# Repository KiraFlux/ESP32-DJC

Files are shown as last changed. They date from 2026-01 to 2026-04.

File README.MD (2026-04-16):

# ESP32 Dual Joystick Controller (DJC)



An open-source remote controller based on ESP32 with dual analog joysticks, designed for DIY robotics projects.

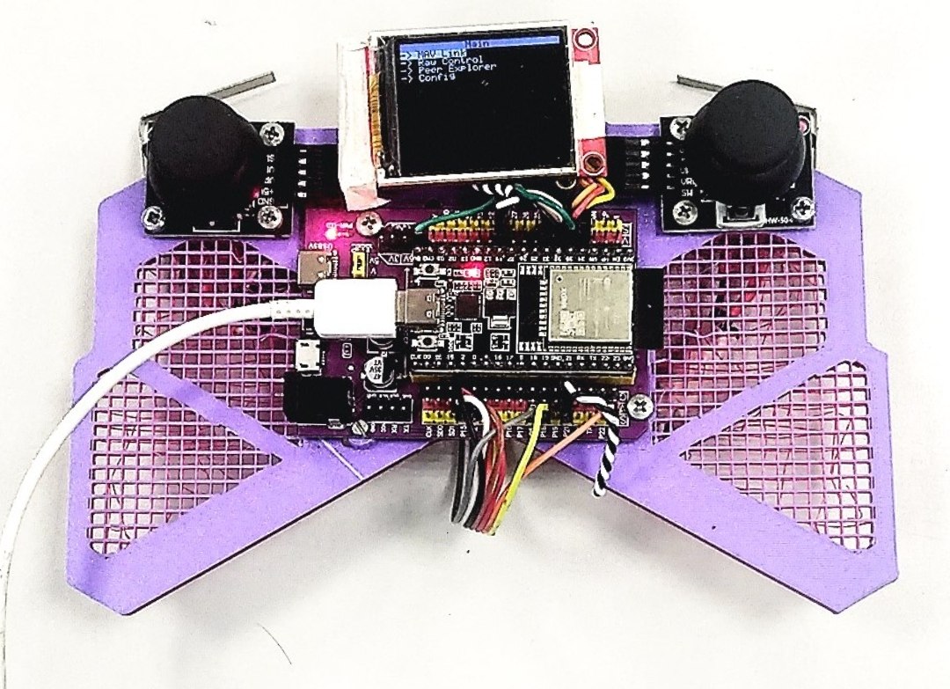
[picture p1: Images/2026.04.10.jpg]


# Software

Firmware is a **PlatformIO** project located in the [`DJC-Firmware`](./DJC-Firmware) directory. All dependencies are declared and managed in [`platformio.ini`](./DJC-Firmware/platformio.ini).

The project uses:
- [KiraFlux/KiraFlux‑Toolkit](https://github.com/KiraFlux/KiraFlux-Toolkit.git)
- [okalachev/MAVLink](https://github.com/okalachev/MAVLink.git)

## Build

A [`makefile`](./DJC-Firmware/makefile) wraps common PlatformIO commands for convenience.

| Command | Action | Note |
| --- | --- | :--- |
| `make` | `pio run` | Compile the project |
| `make u` | `pio run --target upload` | Compile and upload to the ESP32 |
| `make m` | `pio device monitor` | Open serial monitor |
| `make clean` | `pio run --target clean`  | Delete compiled objects |

## Features

| Feature | Status |
| --- | --- |
| Dual joystick with calibration | Implemented |
| ST7735 display (SPI) | Implemented |
| ESPNOW peer discovery & connection | Implemented |
| Raw and MAVLink control modes | Implemented (Basic) |
| Persistent configuration (NVS) | Implemented |
| MAVLink telemetry (partial) | SCALED_IMU, ATTITUDE_QUATERNION, SERIAL_CONTROL messages supported |
| Peer explorer with signal age | Implemented (shows last seen time) |
| On‑screen text input (virtual keyboard) | Implemented (Basic) |

## Usage

The device operates in three modes. Switching between UI Navigation and Control is done with the left button; Virtual Keyboard Input appears automatically when a text field is activated.

| Mode | Purpose | Activation |
| --- | --- | --- |
| **UI Navigation** | Menu navigation and widget interaction | Default after power‑on; return from Control by pressing left button |
| **Control** | Transmit joystick data over ESPNOW | Left button from UI Navigation |
| **Virtual Keyboard Input** | Text entry | Automatically when a text field is activated |

### Input action by Mode

| Input | UI Navigation | Control (Raw) | Control (MAVLink) | Virtual Keyboard Input |
| --- | --- | --- | --- | --- |
| **Left stick X**  | *Unused* | `left_x` | `Yaw` | *Unused* |
| **Left stick Y**  | *Unused* | `left_y` | `Thrust` | *Unused* |
| **Right stick X** | Change value of active widget (left/right) | `right_x` | `Roll` | Move cursor horizontally on keyboard |
| **Right stick Y** | Move cursor between widgets (up/down) | `right_y` | `Pitch` | Move cursor vertically on keyboard |
| **Left button** | Switch to **Control** | Return to **UI Navigation** | Return to **UI Navigation** | **Close virtual keyboard** |
| **Right button**  | Activate selected widget (press, follow link) | *Ignored* | *Ignored* | **Enter the selected key** |

<blockquote>

### Notes

- When the virtual keyboard is active, the left button closes it and does not switch modes.
- In Control mode, the right joystick does not affect the UI – all its movements are transmitted.

</blockquote>

## Known Limitations

- Only ST7735 display is currently supported
- MAVLink telemetry limited to basic IMU/attitude
- No CLI, no sleep

## Roadmap

The project roadmap is maintained in **GitHub Issues**.  
[View open issues and planned features](https://github.com/KiraFlux/ESP32-DJC/issues)

<details>
<summary>Click to see high‑level planned items</summary>

- Finalize power supply documentation
- KiCad schematic and single‑sided PCB shield
- Idle sleep for power saving
- Calibration visual feedback
- Custom peer names/aliases
- Extended MAVLink telemetry
- CLI over Serial
- SSD1306 support
- Hybrid storage (LittleFS + SD card)

</details>

---

# Hardware

## Components

| Group | Component | Part / Model |  Qty  | Notes |
| :--- | :--- | :--- | :---: | :--- |
| **MCU** | ESP32 DevKit | ESP32‑WROOM‑32 (V4) | 1 | Any DevKit variant works |
| **Power** | Li‑ion cell | 18650 1S1P | 1 | Protected or unprotected (BMS required) |
| | Boost converter | XR2981 module | 1 | Step‑up to 5V |
| | Charger (planned) | TP4056 module | 1 | With battery protection (DW01) |
| | Power switch | KCD‑11‑2P | 1 | Rocker switch |
| **Controls** | Joystick | HW‑504 | 2 | Analog, 5V (works at 3.3V) |
| | Micro switch | V‑153‑1C25 (NO) | 2 | External button |
| **Display**  | TFT LCD | ST7735 160×128 SPI  | 1 | With SD‑card slot |
| **Comm** | Radio | ESPNOW (integrated) | – | Direct ESP32‑to‑ESP32 |

## Pin Configuration

| Name | Component | № | Pin | Board Network |
| --- | --- | ---: | ----: | :--- |
| Joystick Left | HW-504 | 1 | GND | Devboard-GND |
| | | 2 | +5V | Devboard-3V3 |
| | | 3 | VRX | Devboard-GPIO_32 |
| | | 4 | VRY | Devboard-GPIO_33 |
| | | 5 | SW | *NC* |
| | | | | |
| Joystick Right | HW-504 | 1 | GND | Devboard-GND |
| | | 2 | +5V | Devboard-3V3 |
| | | 3 | VRX | Devboard-GPIO_34 |
| | | 4 | VRY | Devboard-GPIO_35 |
| | | 5 | SW | *NC* |
| | | | | |
| Button Left | V-153-1C25 | 1 | COM | Devboard-GND |
| | | 2 | NO | Devboard-GPIO_14 |
| | | 3 | NC | *NC* |
| | | | | |
| Button Right | V-153-1C25 | 1 | COM | Devboard-GND |
| | | 2 | NO | Devboard-GPIO_4  |
| | | 3 | NC | *NC* |
| | | | | |
| Display | ST7735 | 1 | LED | Devboard-5V |
| | (Module SPI 160x128)  | 2 | SCK | Devboard-GPIO_18 |
| | | 3 |  MOSI | Devboard-GPIO_23 |
| | | 4 | DC | Devboard-GPIO_22 |
| | | 5 | Reset | Devboard-GPIO_17 |
| | | 6 | CS | Devboard-GPIO_5  |
| | | 7 | GND | Devboard-GND |
| | | 8 | VCC | Devboard-3V3 |
| | | | | |
| Power Switch | KCD-11-2P | 1 | COM | B+ |
| | | 2 | NO | PowerSwitch-NO |
| | | | | |
| Voltage Converter | XR2981 | X1-1 |  OUT+ | Devboard-5V |
| | (Step-up Module) | X1-2 |  OUT- | Devboard-GND |
| | | X2-1 | IN+ | PowerSwitch-NO |
| | | X2-2 | IN- | B- |
| | | | | |
| Battery Sense | Resistor R1 (100 kΩ)  | 1 | – | PowerSwitch‑NO |
| | | 2 | – | Devboard‑GPIO_36 |
| | Resistor R2 (33 kΩ) | 1 | – | Devboard‑GPIO_36 |
| | | 2 | – | Devboard‑GND |
| | Capacitor C1 (0.1 µF) | 1 | – | Devboard‑GPIO_36 |
| | | 2 | – | Devboard‑GND |

<blockquote>    

### NOTE

*NC* means *Not Connected*

Devboard means ESP32 Devkit v4 prototyping board

ST7735 backlight LED **requires** a current‑limiting resistor (440Ω, e.g., two 220Ω in series) when powered from 5V.

Buttons are external micro switches `NO` (normally open) connected between GND and the respective GPIO. Internal pull‑ups are enabled in firmware.

B+ and B- denote battery contacts

</blockquote>

## ESP32 Pin Status

| Left Header | Status | Project Assignment | Right Header | Status | Project Assignment |
| ---: | :----: | :--- | ---: | :----: | :--- |
| **3V3** | ✓ | Logic power | **GND** | ✓ | Common ground |
| **EN** | ✓ | Reset (EN button) | **GPIO23** | ✓ | SPI MOSI (display + SD) |
| **GPIO 36** | ✓ | Battery voltage divider |  **GPIO 22** | ✓ | Display DC |
| **GPIO 39** | ○ | *Free (input only)* | **GPIO 1** | ✓ | UART0 TX (Serial debug) |
| **GPIO 34** | ✓ | Right joystick X | **GPIO 3** | ✓ | UART0 RX (Serial debug) |
| **GPIO 35** | ✓ | Right joystick Y |  **GPIO 21** | ○ | *Free (reserved for I2C SDA)* |
| **GPIO 32** | ✓ | Left joystick X |  **GPIO 19** | ✓ | *SPI MISO (SD card)* |
| **GPIO 33** | ✓ | Left joystick Y |  **GPIO 18** | ✓ | SPI SCK (display + SD) |
| **GPIO 25** | ○ | *Free (DAC)* | **GPIO 5** | ✓ | SPI CS (display) |
| **GPIO 26** | ○ | *Free (DAC)* |  **GPIO 17** | ✓ | Display RESET |
| **GPIO 27** | ○ | *Free* |  **GPIO 16** | ✓ | *SPI CS (SD card)* |
| **GPIO 14** | ✓ | Left button | **GPIO 4** | ✓ | Right button |
| **GPIO 12** | ✗ | *Avoid (MTDI)* | **GPIO 0** | ✓ | BOOT button (use with caution) |
| **GND** | ✓ | Common ground | **GPIO 2** | ○ | *Free (strapping, use with care)* |
| **VIN** | ✓ | 5V input (from XR2981)  |  **GPIO 15** | ○ | *Free (strapping, use with care)* |

<blockquote>

### Legend

| Symbol | Meaning | Note |
| :----: | --- | :--- |
| ✓ | **Occupied** | Already used in the project or reserved |
| ○ | **Free** | Available for new components |
| ✗ | **Unavailable** | **Not** recommended for use (boot conflicts) |

### Notes

| Feature | Used pins | Note |
| ---: | :--- | --- |
| MTDI | **GPIO 12** | controls flash voltage at startup; using it may cause boot instability |
| UART0 | **GPIO 1 / GPIO 3** | Serial |
| BOOT | **GPIO 0** | It can be used as GPIO if held high at boot. |
| | **GPIO 39** | input-only and lacks an internal pull‑up resistor |
| DAC | **GPIO 25 / GPIO 26** | Can be used as DAC outputs |
| Strapping | **GPIO 2 / GPIO 15**  | Freed in this design; safe to use with care (must be low at boot) |

</blockquote>

## Models

3D models (Kompas 3D format) are located in `Models-Legacy` (outdated) and `Models` (under development).  
No production‑ready files yet.

## Backlog

<blockquote>

## v0.1.x

| `v0.1.0` (SSD1306 display) | `v0.1.1` (Using ST7735 display) |
| --- | --- |
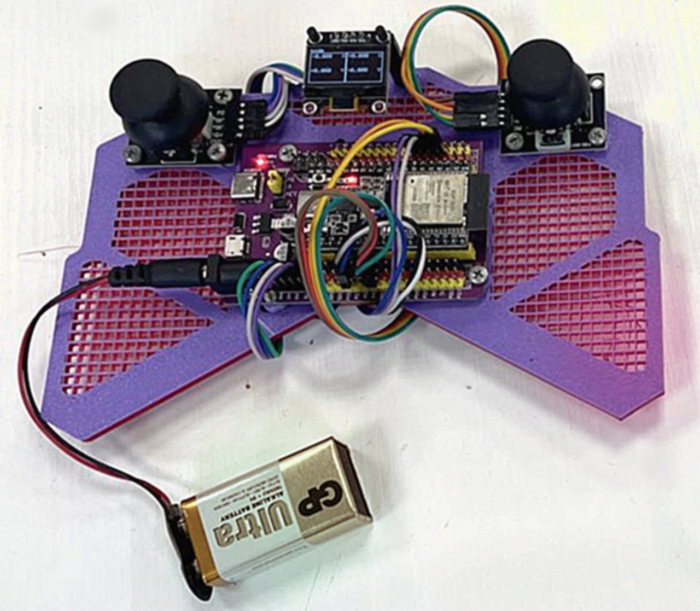
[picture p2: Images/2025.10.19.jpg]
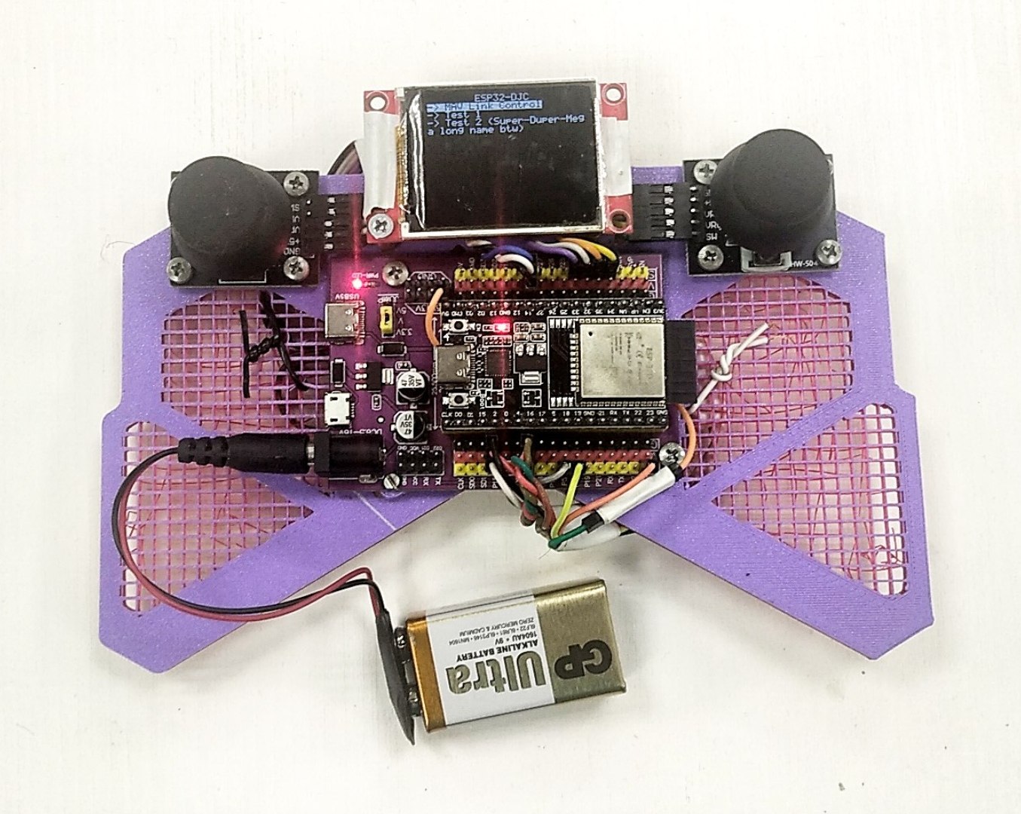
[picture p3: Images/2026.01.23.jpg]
|  |  |

## v0.2.x

| `v0.2.0` (Add microswitch buttons) | `v0.2.1` (Improved cable management) |
| --- | --- |
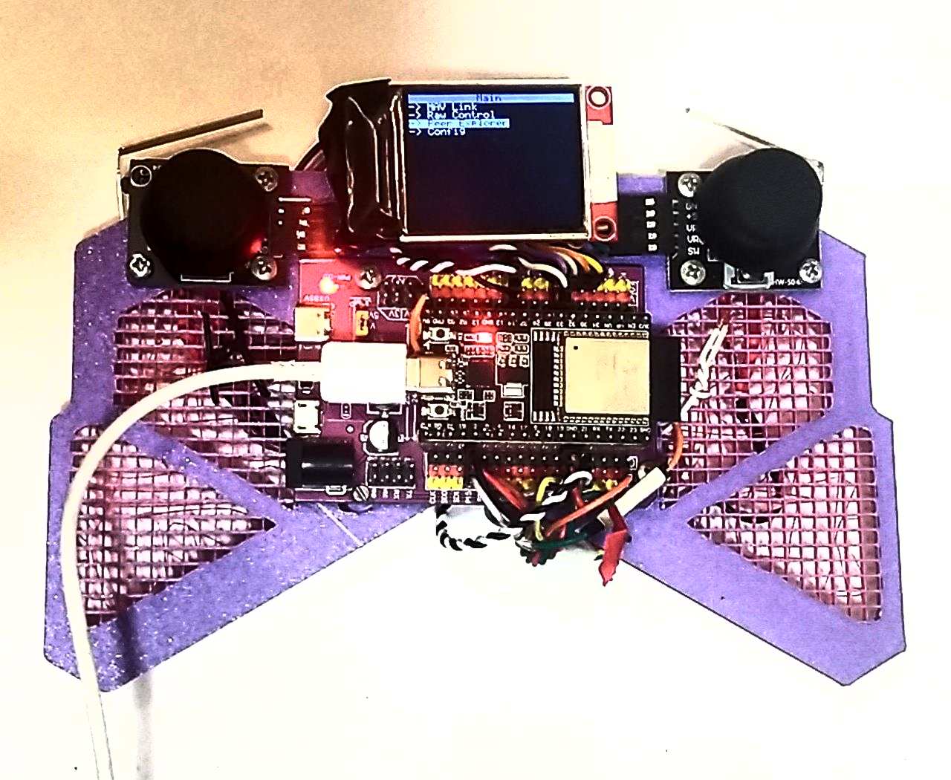
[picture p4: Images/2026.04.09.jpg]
|  |  |

</blockquote>

---

## License

This project is licensed under the **GNU General Public License v3.0 or later** (SPDX: `GPL-3.0-or-later`).

See the [LICENSE](LICENSE) file for the full text.

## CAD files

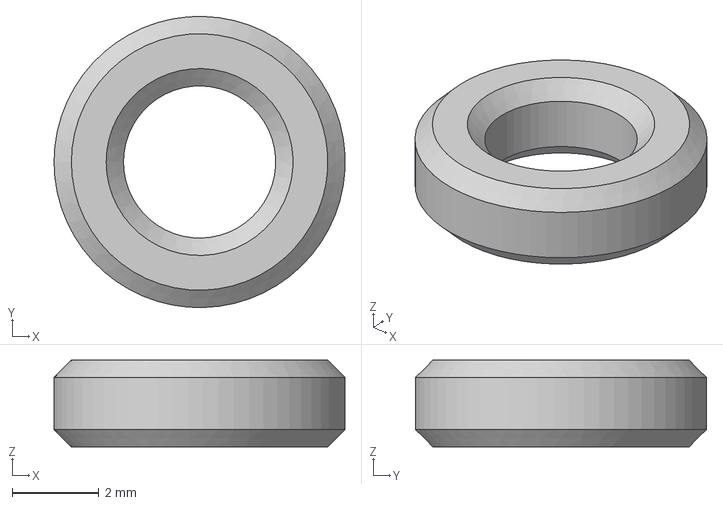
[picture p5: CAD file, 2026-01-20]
Models/Tube.stp
6.70 x 6.70 x 2.00 mm

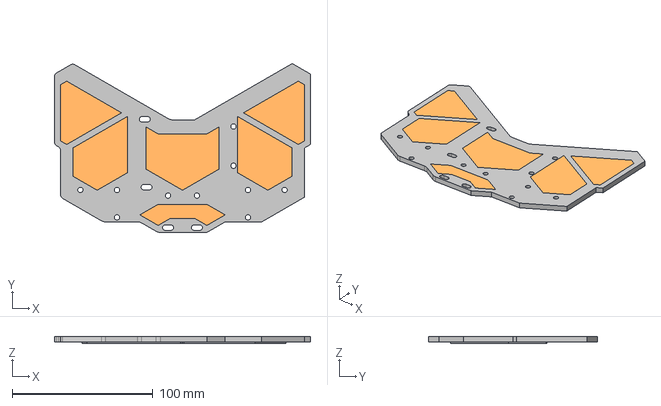
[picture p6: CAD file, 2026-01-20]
Models/Base.stp
181.9 x 120.0 x 5.00 mm

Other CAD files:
Models-Legacy/Tube.3mf
Models/Tube.3mf

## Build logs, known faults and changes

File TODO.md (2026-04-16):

# TODO

## 1. Индикация активного пира на всех страницах
**Проблема:** Сейчас активный MAC виден только в `PeerExplorerPage` (звёздочка). На `MavLinkPage`, `RawControlPage`, `RootPage` пользователь не знает, кому отправляет команды.  
**Решение:** Добавить в `DisplayManager` статусную строку (например, внизу или вверху) с отображением активного пира. Можно последние 4 байта MAC или имя, если добавить заметки.  
**Где:** `DisplayManager::onRender()` запрашивает `control.activeMac()` и выводит справа.

## 2. Подтверждение опасных действий (Reset, Delete peer)
**Проблема:** Кнопка Reset в `ConfigPage` сразу сбрасывает конфиг и перезагружает устройство. Нет диалога подтверждения.  
**Решение:** Реализовать двухэтапное нажатие: первый клик → меняем текст кнопки на "Press again to reset" и запускаем таймер 3 секунды; второй клик в течение таймаута → `storage.reset()`. Или использовать модальное окно, если UI поддерживает.  
**Где:** В `ConfigPage`, обработчик `_reset_storage.callback()`.

## 3. Таймер бездействия и light sleep (энергосбережение)
**Проблема:** ESP32 никогда не спит, батарея садится за несколько часов.  
**Решение:** Добавить `IdleSleepManager`, который сбрасывает счётчик при любом движении стиков (через `InputHandler::controllerValues()`) или нажатии кнопок. При бездействии > N минут (например, 10) — `esp_light_sleep_start()`. При пробуждении переинициализировать ESP-NOW и восстановить соединение к активному пиру.  
**Где:** Новый модуль `src/djc/IdleSleepManager.hpp`, вызывать его `poll()` в `loop()`.

## 4. Визуальный фидбек калибровки джойстиков
**Проблема:** При первом запуске или после сброса вызывается `periphery.tune()`, которая блокирует всё на ~100 мс, а пользователь видит застывший экран.  
**Решение:** Показывать на дисплее сообщение "Calibrating... move joysticks", возможно прогресс-символами. После калибровки — автоматически сохранить конфиг.  
**Где:** В `main.cpp` перед вызовом `tune()` добавить принудительный рендеринг через `DisplayManager` (минуя UI) или отправить событие UI.

## 5. Полноценный MAVLink: телеметрия и управление
**Проблема:** `MavLinkPage` обрабатывает только `SCALED_IMU` и `SERIAL_CONTROL`. Нет отображения высоты, напряжения, спутников, режима полёта.  
**Решение:** Добавить парсинг:
- `GLOBAL_POSITION_INT` → относительная высота, lat/lon.
- `SYS_STATUS` → напряжение батареи, ток, заряд.
- `HEARTBEAT` → режим автопилота (стабилизация, альтхолд, loiter и т.д.).  
Обновлять соответствующие виджеты на странице.  
**Где:** `MavLinkPage::onMavLinkMessage()`.

## 6. CLI (Command Line Interface) через Serial
**Проблема:** Отладка и настройка без экрана невозможны. Нужен простой shell.  
**Решение:** Интегрировать легковесную библиотеку (например, ESP-Shell) и добавить команды:
- `peers` — список обнаруженных MAC из `PeerExplorer` (последние активные).
- `connect <MAC>` — подключиться к пиру.
- `disconnect` — отключиться.
- `mode [raw|mavlink]` — переключить текущий режим.
- `reset` — сбросить конфиг.
- `save` — сохранить конфиг.
- `info` — статус (активный MAC, режим, напряжение батареи).  
**Где:** Новый модуль `src/djc/CLI.hpp`, инициализация в `setup()`.

## 7. Заметки о пирах (имена для MAC)
**Проблема:** Пользователь видит только MAC-адреса, что неудобно для идентификации (дрон, робот, второй дрон).  
**Решение:** Добавить в `Config` структуру `PeerNote { Mac mac; char name[16]; }` и `Box<PeerNote>`. На странице "Peer Notes" отображать список с именами, возможность добавлять/редактировать/удалять. В `PeerExplorerPage` для известных MAC подставлять имя.  
**Где:** `src/djc/Config.hpp`, новая страница `PeerNotesPage`, изменения в `PeerExplorerPage` для отображения имени.

## 8. Автоматическое добавление устройств по Heartbeat
**Проблема:** Сейчас пользователь должен кликнуть на устройство в `PeerExplorerPage`, чтобы подключиться. Хорошо бы при получении heartbeat от нового устройства показывать уведомление с предложением добавить в избранное/заметки.  
**Решение:** В `Control` при получении пакета от неизвестного MAC анализировать, является ли он heartbeat (по сигнатуре). Если да — сохранять MAC во временный буфер и через UI показывать всплывающее сообщение (например, через `ui.addEvent()` и специальный виджет уведомлений).  
**Где:** `Control::onReceiveFromUnknown`, интеграция с `DisplayManager` для отображения уведомлений.

## 9. Выбор типа дисплея через флаг компиляции
**Проблема:** Сейчас жёстко привязан ST7735. Хочется поддержать SSD1306.  
**Решение:** В `platformio.ini` добавить `-DDISPLAY_TYPE=ST7735` или `SSD1306`. В `prelude.hpp` условно подключать нужный драйвер и определять пины.  
**Где:** `prelude.hpp`, `Periphery.hpp` (пины DC/RESET).

## 10. Документация по питанию (сейчас только USB, нет шилда)
**Проблема:** В проекте отсутствует описание автономного питания, пользователи вынуждены питать плату только через USB.  
**Решение:** Дополнить README разделом "Power Supply" с описанием текущего способа (USB) и планов по аккумулятору. Указать требования к току, напряжению.  
**Где:** `README.md`, раздел Hardware или новый подраздел Power.

## 11. Автономное питание от аккумулятора 18650 (1S1P) с boost-конвертером до 5В
**Проблема:** Устройство не может работать от батареи, что ограничивает его применение в полевых условиях.  
**Решение:** Спроектировать цепь питания: защита от переразряда, зарядный контроллер (TP4056 или аналоги), boost-конвертер (MT3608, SX1308 и т.п.) до 5В для подачи на devkit-плату.  
**Где:** Схема в KiCad, тестовый макет, затем интеграция в шилд.

## 12. Разработка шилда для devkit-платы (ESP32 DevKit)
**Проблема:** Подключение джойстиков, кнопок, дисплея выполнено макетными проводами — ненадёжно и неудобно.  
**Решение:** Спроектировать одностороннюю печатную плату (ЛУТ, тонерная технология) для установки на ESP32 DevKit. На шилде разместить:
- разъёмы для двух HW-504,
- разъёмы для двух микропереключателей,
- посадочное место для ST7735 (или гибкий шлейф),
- цепь питания (boost + защита),
- кнопку сброса (опционально).  
**Где:** Новый каталог `Hardware/Shield/` с файлами KiCad (схема, плата), Gerber-файлы, BOM.

## 13. Принципиальная схема всего устройства в KiCad
**Проблема:** Принципиальная схема отсутствует, что затрудняет отладку, повторение проекта и модификации.  
**Решение:** Создать проект KiCad, нарисовать полную принципиальную схему: ESP32 DevKit (как модуль), подключение периферии (джойстики, кнопки, дисплей), цепь питания, разъёмы.  
**Где:** `Hardware/Schematic/DJC_Controller.sch`, экспорт в PDF и PNG для документации.

---

## Порядок выполнения (рекомендованный)

**Программная часть:**
1. Индикация активного пира (п.1)
2. Таймер бездействия + light sleep (п.3)
3. Подтверждение Reset (п.2)
4. Фидбек калибровки (п.4)
5. MAVLink телеметрия (п.5)
6. CLI (п.6)
7. Заметки о пирах (п.7) – опционально
8. Автоматическое добавление (п.8)
9. Выбор дисплея (п.9)

**Аппаратная часть (параллельно или после стабилизации прошивки):**
10. Документация по питанию (п.10) – быстро
11. Принципиальная схема в KiCad (п.13) – основа для шилда
12. Автономное питание (п.11) – макет, отладка
13. Разработка шилда (п.12) – разводка, изготовление ЛУТ

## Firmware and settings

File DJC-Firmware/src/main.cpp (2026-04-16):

// Copyright (c) 2026 KiraFlux
// SPDX-License-Identifier: GPL-3.0-or-later

#include <Arduino.h>

#include <kf/Logger.hpp>
#include <kf/memory/Storage.hpp>
#include <kf/memory/StringView.hpp>

#include "djc/ConfigManager.hpp"
#include "djc/Control.hpp"
#include "djc/DisplayManager.hpp"
#include "djc/Periphery.hpp"
#include "djc/input/InputHandler.hpp"
#include "djc/input/VirtualKeyboard.hpp"
#include "djc/ui/pages/ConfigPage.hpp"
#include "djc/ui/pages/MavLinkPage.hpp"
#include "djc/ui/pages/PeerExplorerPage.hpp"
#include "djc/ui/pages/RawControlPage.hpp"
#include "djc/ui/pages/RootPage.hpp"

static auto &ui{djc::ui::UI::instance()};

static auto &storage{djc::ConfigManager::instance()};

static auto &virtual_keyboard{djc::input::VirtualKeyboard::instance()};

// services

static djc::Periphery periphery{
    storage.config().periphery,
};

static djc::InputHandler input_handler{
    storage.config().input_handler,
    periphery.right_joystick,
    periphery.left_button_listener,
    periphery.right_button_listener,
};

static djc::Control control{
    storage.config().control,
};

static djc::DisplayManager display_manager{
    periphery.display,
    control,
};

// pages

static djc::ui::pages::RootPage root_page{};

static djc::ui::pages::MavLinkPage mavlink_page{
    root_page,
    control,
};

static djc::ui::pages::RawControlPage raw_control_page{
    root_page,
    control,
};

static djc::ui::pages::PeerExplorerPage peer_explorer_page{
    root_page,
    control,
};

static djc::ui::pages::ConfigPage config_page{
    root_page,
};

void setup() {
    static constexpr auto logger{kf::Logger::create("setup")};

    Serial.begin(115200);
    kf::Logger::writer = [](kf::memory::StringView str) { Serial.write(str.data(), str.size()); };

    storage.load();

    if (not periphery.init()) {
        logger.error("Periphery init failed. Resseting periphery config to defaults");
        storage.config().periphery = djc::Periphery::Config::defaults();
        storage.modified(true);
    }

    if (not storage.config().periphery.joystick_axes_tuned) {
        logger.debug("Tunning axes..");
        periphery.tune(storage.config().periphery);
        storage.modified(true);
    } else {
        logger.debug("Axes already tuned");
    }

    (void) control.init();// TODO: implement halt on error?
    display_manager.init();

    {
        using E = djc::ui::UI::Event;

        input_handler.onLeftButton([]() {
            if (virtual_keyboard.active()) {
                virtual_keyboard.quit();
            } else {
                control.enabled(not control.enabled());
            }

            ui.addEvent(E::update());
        });

        input_handler.onRightButton([]() {
            if (control.enabled()) { return; }

            ui.addEvent(E::widgetClick());
        });

        input_handler.onDirection([](djc::InputHandler::JoystickListener::Direction direction) {
            static constexpr E navigation_event_from_direction[4] = {
                E::pageCursorMove(-1),// Up
                E::pageCursorMove(+1),// Down
                E::widgetValue(-1),   // Left
                E::widgetValue(+1),   // Right
            };

            static constexpr E VirtualKeyboard_event_from_direction[4] = {
                E::widgetValue(0),// Up
                E::widgetValue(1),// Down
                E::widgetValue(2),// Left
                E::widgetValue(3),// Right
            };

            if (control.enabled()) { return; }

            const auto table = virtual_keyboard.active() ? VirtualKeyboard_event_from_direction : navigation_event_from_direction;
            ui.addEvent(table[static_cast<kf::u8>(direction)]);
        });

        // apply page links
        root_page.attach(mavlink_page);
        root_page.attach(raw_control_page);
        root_page.attach(peer_explorer_page);
        root_page.attach(config_page);

        ui.bindPage(root_page);
        ui.addEvent(E::update());
    }

    if (storage.modified()) { storage.save(); }
}

void loop() {
    constexpr kf::math::Milliseconds loop_period{1000 / 50};// 50 Hz
    delay(loop_period);

    const auto now = millis();
    input_handler.poll(now);

    if (control.enabled()) {
        using I = djc::Control::Input;

        control.input({
            .left_x = I::fromReal(periphery.left_joystick.axis_x.read()),
            .left_y = I::fromReal(periphery.left_joystick.axis_y.read()),
            .right_x = I::fromReal(periphery.right_joystick.axis_x.read()),
            .right_y = I::fromReal(periphery.right_joystick.axis_y.read()),
        });
    }
    control.poll(now);
    ui.poll(now);
}

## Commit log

2026-01-20 reset history
    [Base.stp, Tube.3mf, Tube.stp]
2026-02-05 Device.hpp: setupUiRenderConfig -> setupRender
2026-02-13 Device::setupGraphics enchantments
2026-04-06 Add debug log for current init mode
2026-04-06 Fix imu display formatting
2026-04-07 Update device config
2026-04-07 refactor: DeviceState: replace bool with enum
    [main.cpp]
2026-04-07 refactor: left button handler mode select logic
2026-04-09 remove deps on dev state from InputHandler, refactor setup procedure. Control init log fix
    [main.cpp]
2026-04-09 add: device name parameter into Config
2026-04-09 refactor: Button: extract first measure into poll
2026-04-10 remove: DeviceState
2026-04-13 rename: input/Button -> input/LogicalLevelListener
2026-04-13 rename Button -> ButtonListener
2026-04-13 PCB project setup
    [DJC-Shield.kicad_pcb, DJC-Shield.kicad_sch]
2026-04-16 update: README.MD - Pin Configuration - ESP32 Pin Status

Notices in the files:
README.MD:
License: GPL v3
